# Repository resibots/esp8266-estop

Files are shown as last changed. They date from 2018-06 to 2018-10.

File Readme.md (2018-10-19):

# ESP8266-based emergency stop button

This is the code for a wifi emergency stop built with the esp8266 wifi + microcontroller. We used the Adafruit Feather HUZZAH with ESP8266 for our own buttons. The board has battery management included and allows to measure the battery voltage (through a voltage divider).

This device will send UDP packets over the wifi network, following a simple ad hoc protocol described below. The consumer of these packets expects them to arrive at a given frequency. If for some set time, no packet arrived, it would stop our robot. As a result, we lower the risk of the robot not being stopped if there is a problem in the network communication or in the emergency stop itself.

Used pins on the board:

- It will read the current battery voltage (of our 3.7V, 1000mAh battery), using the only ADC (Analogue to Digital Conversion) pin available.
- It will blink a led wired to the pin 5 of the board
- The pin EN (enable) is pulled down when the emergency stop is triggered, switching off the device. This is the only single point of failure we know on this system.

## Configuring the device

There are two sets of parameters. The first ones are hard-coded in the source code, like the signature key (which should hence never be committed). The second set of parameters can be changed through the serial interface (type `h` and Enter to see the options). For more details, have a look at `config.hpp` and `config.cpp`.

## Dependency

We rely on [TickerScheduler] for a basic time-based scheduling of the different tasks which are 1. blinking the led (three tasks) 2. handling the configuration 3. sending heartbeats.

## Remarks

One of the fields of the heartbeat messages is the battery charge level. This information is based on the voltage on the battery and is very noisy. It is apparently mainly due to the ESP8266 Wifi module that disrupts analogue readings.

## Future improvements

### Led blinking based on the button's status

I think that it would be nice to have the blinking pattern of the leds change based on the status of the e-stop. Alternatively, there could be a second pair of LEDs (of a different color) for the status, that would blink only when the battery is low or when the connexion is lost.

### Directly wire the button on the battery

<!-- TODO: show electronic circuitry for this -->
<!-- TODO: BOM -->

Currently, the contactor in the emergency stop is a normally open (NO) one. This means that it lets the current cross it only when the button is pressed. When this happens, it will bridge the enable (EN) pin of the Huzzah board and the ground, cutting the voltage regulator on the board. The main drawback is that in case of miss-connection between the contactor and the Huzzah board, the button will cease to function, in the sense that pressing it would no longer stop the robot.

A solution would be to use a normally closed contactor that would be put between the battery and the microcontroller board. The main drawback of this approach is that we cannot reload the battery when the button is pressed.

To solve both issues, we could consider taking an external reloading circuit, directly connected to the battery. Then, the contactor would cut the connection between the battery/reloader and the main board. Additionally, if the only external Micro-USB port is the one of the reloading circuit, we would avoid the (faint) risk of having the microcontroller be reprogrammed by mistake.

### Make an opening in the button for the Micro-USB port

So that we can reload the battery easily and change the button's configuration if needed.

### Make a 3D-printed stand for the electronic boards

For now the electronics boards are just left floating in the button. We would design a stand for both boards (Huzzah and PCB) to be 3D printed. I think we should take advantage of the fixture for the contactors.

### Design and manufacture a PCB for the electronics

This might be done as a daughter board or as a simpler board with wire connecting it to the Huzzah.

It would also be nice to put a connector for each led, so that the button can be more easily opened.

## Hardware design

A little picture of our button, so that you understand what we mean:

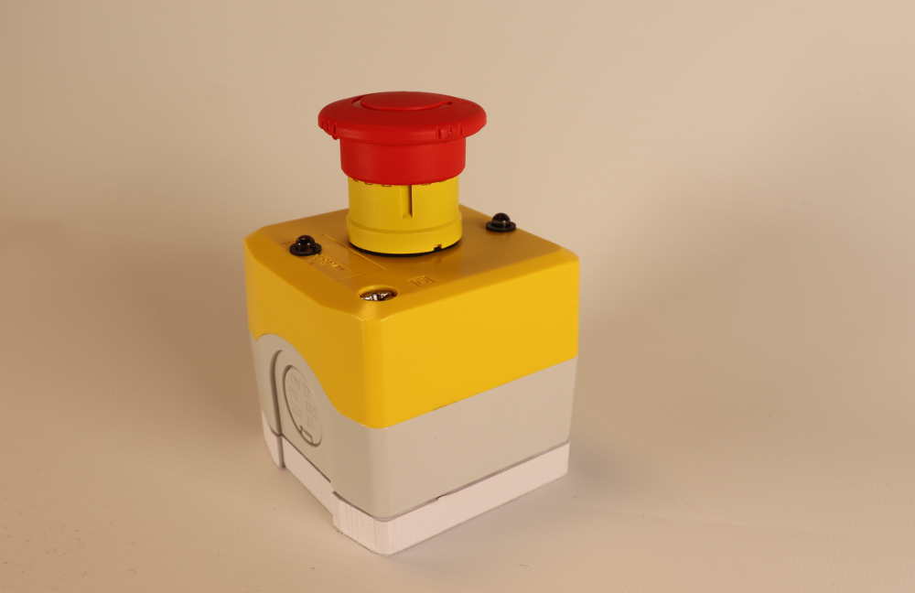
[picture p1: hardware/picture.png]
picture of the emergency button we made


### Electronics

The electronics here are extremely simple :

1. a voltage divider and low-pass filter for the measure of the battery's charge level
2. resistors for current-limitation on the two LEDs

For those who want more details, here is a schematic of the electronics:

see the electronics folder for the schematic

Bill of materials for the board

component reference | value
---------|----------
 R1 & R3 | 1 Mohm
 R2 | 220 Kohm
 R4 | 22 ohm
 C1 | 1 uF
 LED1 & LED2 | blue led (Radio Spares 815-4366)

We also bought

### Mechanical

Bill of materials:

Designation | Radio Spares product number
----------|---------
 Emergency stop button | 330-8587
 Normally open contactor (for the button) | 331-0574

We also made a 3D printed part that would bit below the button, in order to host the too large battery. The design is available as STL in the hardware folder. It was designed with Onshape ([link to the original design](https://cad.onshape.com/documents/043af48d8279ec13bb06e1de/w/d73f08f1384db1234596df65/e/912adaf6e6cce1dc58b794c6)).

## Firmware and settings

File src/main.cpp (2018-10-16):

// Standard
#include <functional> // for `bind`

// Libraries
#include <ESP8266WiFi.h>
#include <SHA256.h>
#include <TickerScheduler.h>
#include <TimeLib.h>
#include <WiFiUdp.h>

// Project-specific classes, functions and variables
// Class in charge of blinking a led
#include "Led.hpp"
// Functions getting current time from an NTP server
#include "ntp.hpp"
// Heartbeat generator and sender for heartbeat
#include "heartbeat.hpp"
// Global variables and settings
#include "globals.hpp"
// Configuration server
#include "config.hpp"

#include "Arduino.h"

//  Object for UDP communication
WiFiUDP Udp;
char packet_buffer[512]; // buffer for incoming and outgoing data

//  Instance of the task scheduler
TickerScheduler scheduler(2 + 3);

// Manage and expose the configuration of the emergency stop
// It also offers a configuration interface either through UDP or serial
// communication.
Configuration conf(Udp, scheduler, Configuration::CommunicationMode::serial);

// Object sending heartbeat heartbeats through the network
Heartbeat heartbeat(conf, Udp, packet_buffer);

void setup(void)
{
    // Initialize the serial port
    Serial.begin(115200);
    Serial.println('\n');

    // Print MAC address, in case we need it for wifi setup
    uint8_t macAddr[6];
    WiFi.macAddress(macAddr);
    Serial.printf("Mac address: %02x:%02x:%02x:%02x:%02x:%02x\n",
        macAddr[0], macAddr[1], macAddr[2], macAddr[3], macAddr[4], macAddr[5]);

    // Initialize EEPROM
    static const uint32_t byte_space = 4 + 2 + 4; // memory space used by the
    // settings: 4 for the IP, 2 for the port, 4 for the heartbeat period
    EEPROM.begin(byte_space);
    conf.load();

    // Connect to the Wifi network
    // We only leave the loop when connected. In the meantime the status is
    // printed to the serial connection.
    WiFi.begin(conf.ssid, conf.password);
    WiFi.config(conf.staticIP, conf.gateway, conf.subnet, conf.dns_server_primary, conf.dns_server_secondary);
    while (WiFi.status() != WL_CONNECTED) {
        delay(500);
        String status = "";
        switch (WiFi.status()) {
        case WL_CONNECTED:
            status = "connected";
            break;
        case WL_NO_SSID_AVAIL:
            status = "no SSID available";
            break;
        case WL_CONNECT_FAILED:
            status = "connection failed";
            break;
        case WL_IDLE_STATUS:
            status = "idle";
            break;
        case WL_DISCONNECTED:
            status = "disconnected";
            break;
        default:
            status = "unknown status";
        }
        Serial.println(status);
    }
    // Once connected, print on the serial port the affected IP address, as well
    // as the MAC address
    Serial.println();
    Serial.print("Connected, IP address: ");
    Serial.println(WiFi.localIP());

    // Setup of UDP communication with the port on which to listen
    Udp.begin(conf.config_port); // used for NTP and configuration (if enabled)

    // Get the time from NTP server
    Serial.println("waiting for Network Time Protocol sync");
    setSyncProvider(getNtpTime);
    // Tells how often the time is synchronised
    // By default, synchronisation is done every five minutes
    // setSyncInterval(3600); // in seconds
    Serial.print("Time status: ");
    switch (timeStatus()) {
    case timeNotSet:
        Serial.println("not set");
        break;
    case timeSet:
        Serial.println("set");
        break;
    case timeNeedsSync:
        Serial.println("needs sync");
        break;
    }

    Serial.print("Listening on UDP port ");
    Serial.println(conf.config_port);

    // Setup the scheduler
    std::function<void(void)> send_heartbeat = std::bind(&Heartbeat::send_heartbeat, &heartbeat, true);
    if (!scheduler.add(0, conf.heartbeat_period, send_heartbeat, true))
        Serial.println("ERROR: Could not create the heartbeat task");
    std::function<void(void)> update_configuration = std::bind(&Configuration::update, &conf);
    if (!scheduler.add(1, 1000, update_configuration, true))
        Serial.println("ERROR: Could not create the configuration task");

    // initialisation of the led blinking class
    // pin for the led: 5
    blinkLed.init(5, &scheduler);
}

void loop()
{
    scheduler.update();
    blinkLed.update();

    delay(10);
}

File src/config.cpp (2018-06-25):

#include "config.hpp"

void Configuration::update()
{
    // If there is incoming data, read it
    int packet_size = read();

    if (packet_size) {
        _buffer[packet_size] = 0;

        // Special case: use wants to [r]ead the current settings
        if (_buffer[0] == 'r') {
            sprintf(_buffer,
                "Recipient IP   %s\n"
                "Recipient port %u\n"
                "Heartbeat period   %u\n",
                recipient_ip.toString().c_str(),
                recipient_port,
                heartbeat_period);
        }
        else if (_buffer[0] == 's') {
            // save the settings in EEPROM if the change was successful
            if (save())
                sprintf(_buffer, "Settings saved\n");
            else
                sprintf(_buffer, "Settings failed to be saved\n");
        }
        else if (_buffer[0] == 'h') {
            help_message(true);
        }
        else if (packet_size > 2 && _buffer[1] == ' ') {
            // Store the parameters in a String and remove empty characters
            String parameter(_buffer + 2);
            parameter.trim(); // remove front and trailing spaces but above
            // all newline character

            // Select the command to execute based on first received
            // character
            switch (_buffer[0]) {
            case 't': // update heartbeat period
            {
                // retrieve the desired period
                uint32_t new_heartbeat_period = labs(parameter.toInt());

                // tell whether the setting change was successful
                bool success = false;
                // Change the period of the heartbeat task (change value and
                // update task)
                success = _scheduler.changePeriod(0, new_heartbeat_period)
                    & _scheduler.disable(0) // required for the change to be
                    & _scheduler.enable(0); // effective
                if (!success)
                    sprintf(_buffer, "ERROR: Could not change the heartbeat period\n");
                else {
                    heartbeat_period = new_heartbeat_period;
                    sprintf(_buffer, "New period : %u ms\n", heartbeat_period);
                }

                break;
            }
            case 'a': // change the recipient address
            {
                // attempt to update the recipient IP ( andchecking if the
                // IP is valid)
                if (!recipient_ip.fromString(parameter)) {
                    sprintf(_buffer, "ERROR: Could not change the "
                                     "recipient IP from string %s\n"
                                     "Current address %s\n",
                        parameter.c_str(), recipient_ip.toString().c_str());
                }
                else {
                    sprintf(_buffer, "New recipient IP : %s\n",
                        recipient_ip.toString().c_str());
                }

                break;
            }
            case 'p': // change the recipient port
            {
                // retrieve the desired port number
                uint16_t new_port = labs(parameter.toInt());

                // check that the port is in the allowed range 0..65535
                // and use it
                if (new_port > 65535) {
                    sprintf(_buffer, "ERROR: Could not change the "
                                     "recipient port to%u\n",
                        new_port);
                }
                else {
                    recipient_port = new_port;
                    sprintf(_buffer, "New recipient port : %u\n",
                        recipient_port);
                }

                break;
            }
            case 'd': // change the led's duty cycle
            {
                uint8_t new_duty_cycle = labs(parameter.toInt());

                if (new_duty_cycle > 99 || new_duty_cycle < 1) {
                    sprintf(_buffer, "ERROR: requested duty cycle %u% "
                                     "is out of range of [1, 99].\n",
                        (int)new_duty_cycle);
                }
                else {
                    blinkLed.set_duty_cycle(new_duty_cycle);
                    sprintf(_buffer, "Duty cycle changed to %u%\n",
                        (int)new_duty_cycle);
                }
                break;
            }
            case 'e': // change the led's blink period
            {
                uint16_t new_period = labs(parameter.toInt());

                if (!blinkLed.set_period(new_period)) {
                    sprintf(_buffer, "ERROR: failed to set blinking "
                                     "period to %u (probably due to "
                                     "TickerScheduler)\n",
                        new_period);
                }
                else {
                    sprintf(_buffer, "Blink period changed to %u\n",
                        new_period);
                }

                break;
            }
            }
        }
        else {
            help_message(false);
        }

        write();
    }
}

void Configuration::load()
{
    uint32_t temp_ip;
    EEPROM.get(0, temp_ip);
    recipient_ip = temp_ip;
    EEPROM.get(4, recipient_port);
    EEPROM.get(6, heartbeat_period);
    Serial.printf(
        "Recipient IP   %s\n"
        "Recipient port %u\n"
        "Heartbeat period   %u\n",
        recipient_ip.toString().c_str(),
        recipient_port,
        heartbeat_period);
}

bool Configuration::save()
{
    EEPROM.put(0, (uint32_t)recipient_ip);
    EEPROM.put(4, recipient_port);
    EEPROM.put(6, heartbeat_period);
    return EEPROM.commit();
}
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

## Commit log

2016-10-19 Add code to blink a led
2017-09-11 add task to print time
2017-09-12 complete HMAC computation prototype
2017-09-13 prototype that makes ESP crash
    [pulse.cpp, simple_http_client.cpp]
2017-09-14 Fix and enable pulse again
    The problem was a pointer that had not been allocated memory space.
    Shame on me!
    [pulse.cpp, simple_http_client.cpp]
2017-09-14 describe the binary frame protocol
2017-09-19 Document a public method of Led
2017-09-19 refactor to allow for sending the battery charge
2017-09-19 battery charge being handled by pulse, it is no longer needed here.
    [simple_http_client.cpp]
2017-10-18 Change heartbeat protocol. Instead of using milliseconds, we have a counter starting at each second. This way, we can guarantee that the second number is always increasing for a given second (timesta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
2018-06-26 Change computation of battery charge percentage
2018-10-16 remove hard-coded led pin number
2018-10-16 change pin for led from 4 to 5
2018-10-19 add the hardware
    [schematic.fzz]
